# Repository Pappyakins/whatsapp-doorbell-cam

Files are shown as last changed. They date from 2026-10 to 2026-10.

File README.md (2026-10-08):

# WhatsApp Doorbell Cam

A standalone PIR + camera doorbell that snaps a photo of your visitor and delivers it straight to your WhatsApp.

**How it works:** An HC-SR501 PIR watches the doorway on microamps → motion wakes the ESP32-CAM from deep sleep → it snaps a photo → POSTs the JPEG to a small webhook on your home server → the server forwards it to your WhatsApp as a photo message captioned "🔔 Someone's at the door! (Front door, \<time\>)".

No cloud accounts, no subscriptions, no apps phoning home. Your server, your WhatsApp.

> **Status:** build guide complete. Firmware and server photo endpoint are in progress.

## Parts

| Part | Notes |
|---|---|
| AI-Thinker ESP32-CAM module | OV2640 camera, onboard flash LED. ~C$12–18 on AliExpress |
| FTDI USB-to-TTL programmer (3.3V) | **Required** — the ESP32-CAM has no USB port; you cannot flash it without this |
| HC-SR501 PIR motion sensor | The 5-pack variety — you'll have spares |
| 5V USB power adapter | Simplest power option |
| — or — 18650 cell + TP4056 charger (with protection) + 5V boost module | For a truly wireless install |
| 470µF electrolytic capacitor | Across 5V/GND near the board — kills the brownout resets these boards are famous for |
| Jumper wires | |
| 3D-printed enclosure | See Enclosure |

## Power

- Taking a photo + WiFi POST: ~250–300mA for ~10–15 seconds, roughly 1mAh per visitor.
- Deep sleep on a stock board: ~5mA idle (the onboard AMS1117 regulator's quiescent current dominates, not the chip) → about 3–4 weeks on a 3000mAh 18650.
- Same cell with the regulator-bypass mod (feed 3.3V direct, remove the AMS1117): ~0.1mA idle → several months.
- **Recommendation:** USB 5V wall wart if there's an outlet near the door. Zero power anxiety, no charging, no mods. Battery only if the spot truly has no outlet.

## Wiring

- 5V supply → ESP32-CAM `5V` pin, GND → `GND`. 470µF cap across 5V/GND close to the board.
- PIR: `VCC` → 5V, `GND` → GND, `OUT` → **GPIO 13** (RTC-capable, so the ESP32 wakes from deep sleep directly on it — no transistor hack needed).
- Flashing only: FTDI `TX` → `U0R`, `RX` → `U0T`, `GND` → `GND`, `GPIO 0` → `GND` while flashing, then press `RST`. Release GPIO 0 after the flash.

## Server

New endpoint on the home server (same box that runs the text-alert webhook):

- `POST /api/doorbell-photo` — multipart form with the JPEG (`photo`) plus the shared `token`.
- The server saves the photo and sends it to WhatsApp via the Evolution API `sendMedia` call, captioned "🔔 Someone's at the door! (Front door, \<time\>)".
- The same 3-minute cooldown as the text alerts applies, so a lingering visitor doesn't spam you.

## Firmware (in progress)

1. PIR goes high → ESP32 wakes from deep sleep (ext1 wake on GPIO 13).
2. Camera init, snap at SVGA (800x600 — good detail, small enough to POST fast).
3. Optional: flash LED on GPIO 4 fires for night captures.
4. WiFi connect (10s timeout) → POST photo → wait for PIR line to drop → back to deep sleep.

## Enclosure

- 3D-printable case with a window for the PIR Fresnel dome (**must stay exposed**), a window for the camera lens, and an optional flash-LED window if you use it as a night illuminator.
- Mount ~1.5m beside the door, aimed down the walkway, away from direct sun and HVAC vents.
- Keep the ESP antenna area clear of metal.

## 3D-printed case (`case/`)

Ready-to-print STLs, generated by `case/generate_case.py` (true CSG solids
built with manifold3d via the project venv at `../.venv` — edit the
dimensions there if your boards differ). Both STLs are single watertight
solids that open directly in Bambu Studio; assembly dimensions, exploded
view, parts list and wiring are in `case/doorbell-cam-assembly-drawing.pdf`
(generated by `case/make_drawing.py`):

- `doorbell-cam-body.stl` — 96 × 70 × 34.5 mm pebble body with a smooth
  rounded-rectangle silhouette (12 mm corner radius), 2.5 mm walls. The
  front face has two flush circular bezels: a **26 mm bore** for the
  HC-SR501 Fresnel dome and a **20 mm bore** covering the ESP32-CAM lens
  + flash LED. 18650 battery bay (saddle cradle, end stops, zip-tie
  slots), main + charger USB notches in the bottom wall. Four Ø8 corner
  bosses take M3 brass heat-set inserts.
- `doorbell-cam-lid.stl` — matching rounded back lid, 5 mm, with M3
  clearance holes + Ø5.6 counterbores (socket heads sit flush, recesses
  face outward) and two 5 mm round holes for wall screws.

Print settings: PETG recommended (porch/sun/heat), 0.2 mm layers, 3 walls,
15% infill. **No supports needed** — print the body front-face-down
(windows on the build plate) and the lid flat.

Assembly:
1. Mount the boards inside the body with M2.5 standoffs, VHB tape, or hot
   glue, lining the PIR dome and camera lens up with their windows.
2. Thread the USB cable through the bottom notch.
3. Screw the lid to the wall through the two 5 mm holes (screw heads inside).
4. Close the body onto the lid with four M3 × 10 screws (heads sit
   flush in the lid counterbores).

## Build order

1. Order the ESP32-CAM + FTDI programmer (a few weeks on AliExpress).
2. Firmware + server photo endpoint.
3. Flash and bench-test on the desk.
4. Print the case.
5. Mount by the door.

## Security

Never commit WiFi credentials or the API token to this repo. Keep them in a local secrets file on the device and the server only.

---
Powered by @jakinsCraft

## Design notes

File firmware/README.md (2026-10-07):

# Doorbell Cam firmware

Arduino sketch for the AI-Thinker ESP32-CAM. Deep-sleeps until the PIR
wakes it, snaps an 800x600 JPEG, POSTs it to the home server, blinks the
flash LED, and sleeps again.

## Flashing

1. Install the Arduino IDE + ESP32 board support (esp32 by Espressif).
2. Board: **AI Thinker ESP32-CAM**. Partition scheme: default is fine.
3. Copy `config.h.example` to `config.h` and fill in your Wi-Fi details,
   the server URL, and the device token (Muse gives you the token —
   it must match `doorbell_token.txt` on the server).
4. Connect the FTDI programmer: 3.3V -> 3V3, GND -> GND, TX -> U0R,
   RX -> U0T. Hold **GPIO0 to GND** while pressing RST to enter
   download mode, then upload.
5. **Never commit `config.h`.** It is gitignored.

## Wiring

| ESP32-CAM | Other |
|---|---|
| 5V | Boost +5V out  |
| GND | GND (common) |
| GPIO13 | HC-SR501 OUT |
| GPIO4 | (on-board flash LED) |

- HC-SR501 VCC -> 5V (it wants 4.5–12V), GND -> GND.
- HC-SR501 output is 3.3V logic — safe straight into GPIO13.
- Set the PIR sensitivity/time pots mid-range; the jumper on **H**
  (retrigger) is recommended.
- 18650 (+) -> TP4056 B+/B-, TP4056 OUT -> 5V boost in,
  boost out -> ESP32-CAM 5V. Common ground everywhere.

## Power

Deep sleep draws microamps; the board is awake only ~10–20 seconds per
visitor. A 3000mAh 18650 lasts roughly 1–3 months depending on foot
traffic. The printed case (v3+) has the battery bay, charger USB notch,
and zip-tie retainer groove.

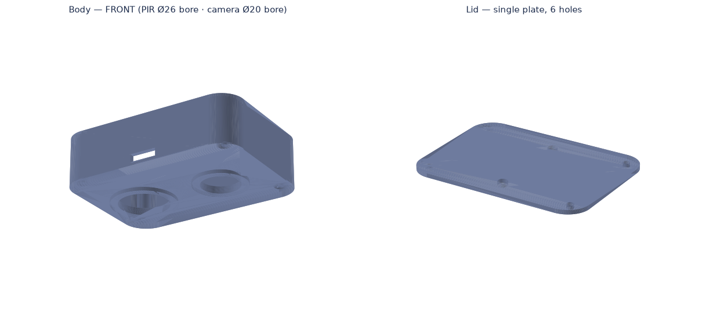
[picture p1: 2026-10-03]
case/preview.png

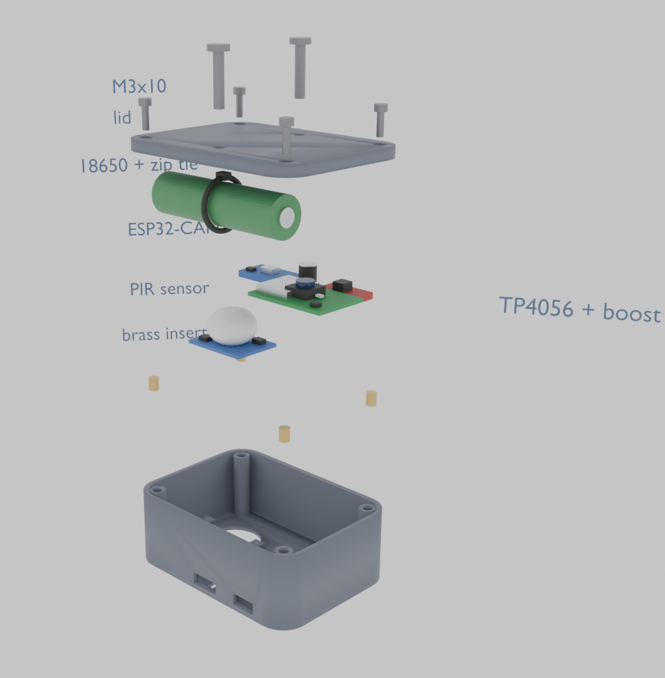
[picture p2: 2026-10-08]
case/render-exploded.png

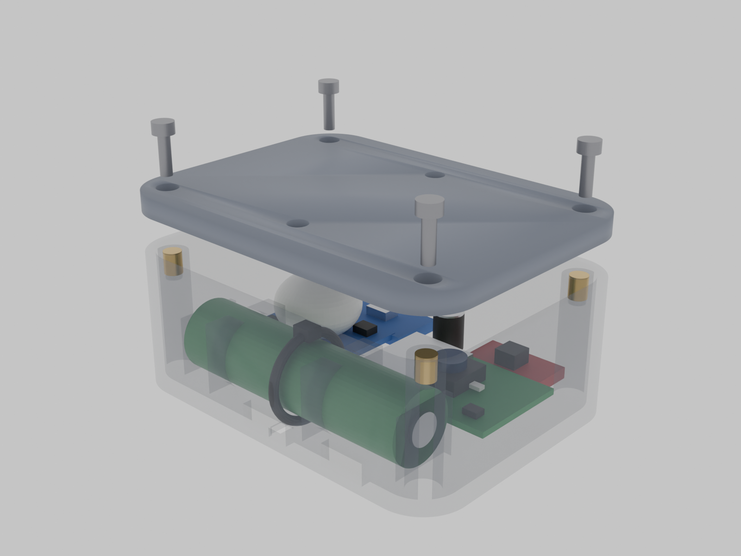
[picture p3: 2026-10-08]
case/render-fitted.png

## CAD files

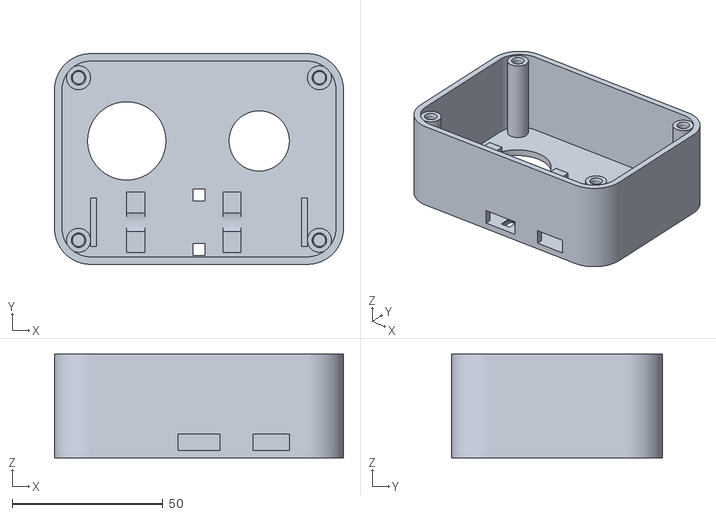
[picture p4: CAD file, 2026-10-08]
case/doorbell-cam-body.stl
96.0 x 70.0 x 34.5

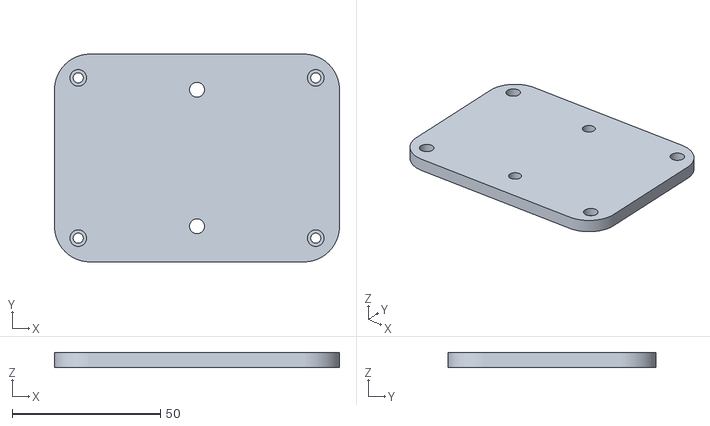
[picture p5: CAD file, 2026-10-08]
case/doorbell-cam-lid.stl
96.0 x 70.0 x 5.00

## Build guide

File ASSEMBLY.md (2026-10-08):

# Doorbell Cam — Assembly Instructions

## Parts checklist

| Qty | Part |
|---|---|
| 1 | Printed body (`doorbell-cam-body.stl`) |
| 1 | Printed lid (`doorbell-cam-lid.stl`) |
| 1 | ESP32-CAM (AI-Thinker, OV2640) |
| 1 | HC-SR501 PIR sensor |
| 1 | 18650 cell, flat-top, 65–68 mm (e.g. Samsung 30Q) |
| 1 | TP4056 charger board **with protection**, micro-USB port |
| 1 | 5V boost converter module |
| 1 | 470µF electrolytic capacitor |
| 4 | M3 brass heat-set inserts (≈4.6 mm OD × 5.7 mm long) |
| 4 | M3×10 socket-head screws (lid → body) |
| 2 | Wall screws + anchors (for the 5 mm lid holes — sized to your wall) |
| 1 | Small zip tie (≈2.5 mm wide) |
| — | Jumper wire, solder |
| — | VHB tape or hot glue (board mounting) |

Tools: 3D printer, soldering iron (also used for the inserts), FTDI USB-to-TTL
programmer (3.3V) for flashing, small Phillips screwdriver, flush cutters.

## 1. Print the case

- PETG recommended (porch, sun, heat). 0.2 mm layers, 3 walls, 15% infill.
- **Body: print front-face-down** (the flat face with the two round bores goes
  on the build plate). **Lid: print flat** (5 mm; the counterbore recesses
  are on the top face). No supports needed for either.

## 2. Install the brass inserts

- Heat your soldering iron to ~200°C (a dedicated insert tip helps, plain tip works).
- Press one M3 insert into each of the 4 corner boss holes, straight down
  until the top sits **flush** with the boss face. Let cool before touching.
- The holes have a small lead-in funnel — the insert should start easily by hand.

## 3. Flash the ESP32-CAM (do this before it goes in the case)

1. Copy `firmware/config.h.example` to `firmware/config.h`; fill in Wi-Fi,
   server URL, and device token.
2. FTDI → ESP32-CAM: 3.3V→3V3, GND→GND, TX→U0R, RX→U0T.
3. Hold **GPIO0 to GND**, press RST, upload the sketch, then release GPIO0.
4. Full flashing details: `firmware/README.md`.

## 4. Wire the power chain (on the bench)

```
18650 (+) → TP4056 B+      18650 (−) → TP4056 B−
TP4056 OUT+ → boost IN+     TP4056 OUT− → boost IN−
boost OUT+ (+5V) → ESP32-CAM 5V pin
boost OUT− (GND) → common ground
470µF capacitor across +5V / GND, as close to the ESP32-CAM as possible
```

- Double-check 18650 polarity before connecting — reverse polarity can kill
  the charger (the protection board is a backstop, not a plan).
- Common ground everywhere: battery −, TP4056, boost, ESP32-CAM, PIR.

## 5. Wire the PIR

| HC-SR501 | Goes to |
|---|---|
| VCC | +5V rail |
| GND | GND |
| OUT | ESP32-CAM **GPIO13** |

- PIR output is 3.3V logic — safe directly into GPIO13.
- Set the sensitivity/time pots to mid-range; put the jumper on **H**
  (retrigger mode).

## 6. Mount the boards in the body

- **ESP32-CAM:** behind the 20 mm bore, lens centred in the hole, **board
  long-side horizontal**. The flash LED sits beside the lens inside the same
  bore. Fix with VHB tape or a dab of hot glue — keep the ESP antenna area
  clear of metal.
- **PIR:** behind the 26 mm bore with the white Fresnel dome poking into it.
  Same fixing method.
- Keep the boards 2–3 mm off the front plate if you can; the bores were
  positioned so nothing fouls the battery bay.

## 7. Fit the battery

1. Lay the 18650 in the saddle cradle (axis along X, between the end stops).
2. Feed the zip tie **up through one floor slot** (from the outside), **over
   the cell**, and **down through the other slot**.
3. Cinch it so the buckle seats in the shallow groove on the outer face.
   Snug, not crushing. Trim the tail.

## 8. Fit the charger and boost boards

- Tape the TP4056 and boost module down **beside** the cradle with VHB tape.
- Line the TP4056's USB port up with the charger notch in the bottom wall —
  that's how you'll plug in to recharge without opening the case.

## 9. Bench-test before closing

1. Power up, wave a hand in front of the PIR.
2. You should get a WhatsApp photo captioned "🔔 Someone's at the door!".
3. If nothing arrives: check the server endpoint is up, the token matches,
   and the PIR OUT line actually goes high (multimeter on GPIO13).

## 10. Mount it

1. Hold the **lid** against the door frame/wall at ~1.5 m height, beside the
   door, aimed down the walkway — away from direct sun and HVAC vents.
2. Fix the lid with 2 screws through the 5 mm holes (**screw heads inside**).
3. Offer the body up and close it with the 4× M3×10 screws into the inserts —
   heads sit flush in the lid counterbores (recesses face outward, away
   from the body). Don't overtighten — snug is enough in PETG.

## Recharging

Plug a USB cable into the TP4056 port through the charger notch. The charger's
onboard LED shows charging/full. A 3000 mAh cell lasts roughly 3–4 weeks on a
stock board (less with heavy foot traffic); the regulator-bypass mod in the
main README stretches that to months.

## Troubleshooting

| Symptom | Likely cause |
|---|---|
| Photo never arrives | Token mismatch, server endpoint down, or no Wi-Fi at the door |
| Board resets when snapping | Missing/weak 5V — check the 470µF cap and boost output under load |
| Constant false triggers | PIR facing sun/vent, sensitivity pot too high |
| Insert spins in boss | Hole printed oversize — a drop of CA glue around the insert saves it |
| Case won't close on lid | Check nothing (boost board, wires) stands taller than the bosses |

---
Powered by @jakinsCraft

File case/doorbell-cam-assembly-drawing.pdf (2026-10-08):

LID (B) — OUTSIDE FACE, 5 THICK

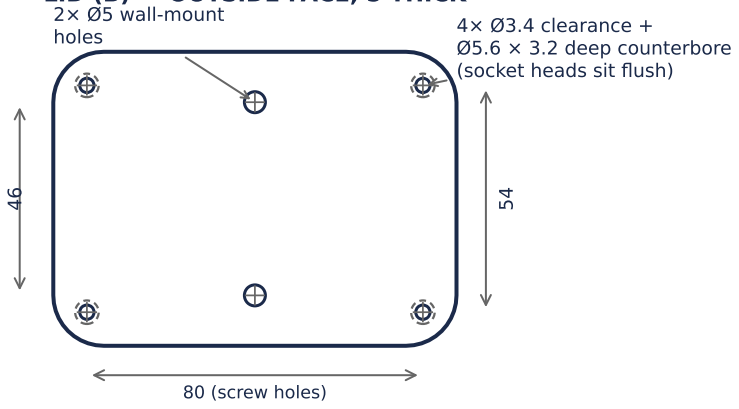
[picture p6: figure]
80 (screw holes); 4× Ø3.4 clearance + Ø5.6 × 3.2 deep counterbore (socket heads sit flush); 2× Ø5 wall-mount holes
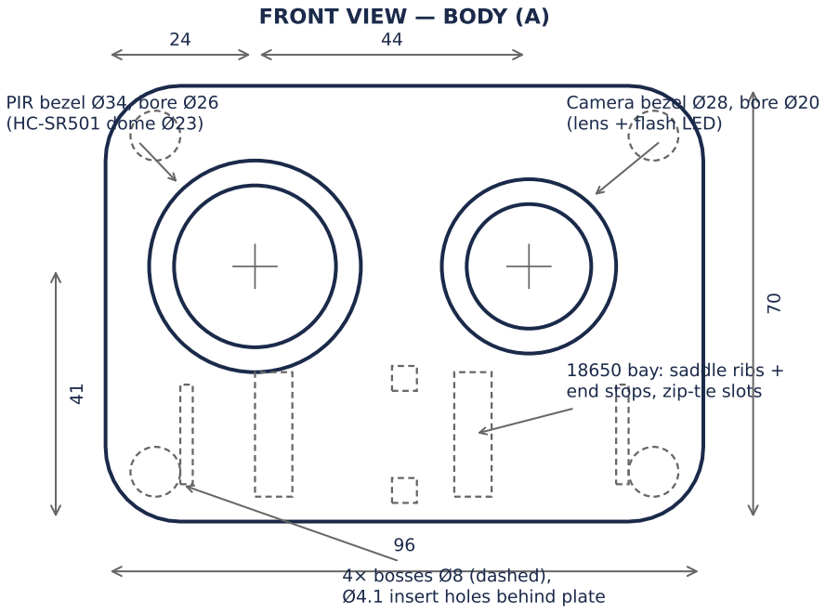
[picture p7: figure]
18650 bay: saddle ribs + end stops, zip-tie slots; FRONT VIEW — BODY (A); PIR bezel Ø34, bore Ø26 (HC-SR501 dome Ø23); Camera bezel Ø28, bore Ø20 (lens + flash LED); 4× bosses Ø8 (dashed), Ø4.1 insert holes behind plate

SIDE VIEW — DEPTHLID (B)

body depth 34.5 lid 5

hollow interior
(2.5 walls all round)

BOTTOM VIEW — USB NOTCH

notches 5.5 tall behind front plate: main USB x 41–55 (14 wide), charger USB x 66–78 (12 wide)

# WhatsApp Doorbell Cam — Pebble Enclosure

Dimensioned views · Body (A) and Lid (B) · STLs in the case folder

Rev 2026-10-08

Units: mm · JakinsCraft

PRINTING
- PETG recommended (porch sun/heat). 0.2 mm layers, 3 walls, 15% infill.
- Body prints FRONT-FACE-DOWN; lid prints flat. No supports needed.
- Both STLs are single watertight solids — they open directly
in Bambu Studio (fixed 2026-10-02; the old files were not).

BEFORE A LONG PRINT
- Test-fit your parts: HC-SR501 dome is Ø23 (bore Ø26); ESP32-CAM boards vary slightly between sellers. Print, check, then commit.
- USB power cable routes out through the bottom notch.
- Press the 4 M3 brass inserts into the bosses (≈200°C iron)
before wiring anything. | Powered by @jakinsCraft

EXPLODED VIEW (schematic, front → back)
lens + flash face the Ø20 bore · PIR dome faces the Ø26 bore

A · BODY

shell with bosses

BOARDS

ESP32-CAM · HC-SR501

B · LID

closes the back

4× M3×10
socket-head
+ brass inserts

charger USB reaches the bottom notch

# | Part | Qty

A | Enclosure body (3D print, PETG) | 1
B | Enclosure lid (3D print, PETG) | 1
1 | ESP32-CAM (AI-Thinker) + OV2640 | 1
2 | HC-SR501 PIR motion sensor | 1
3 | M3 × 10 socket-head screws | 4
4 | M3 brass heat-set inserts | 4
5 | 18650 cell + TP4056 + 5V boost + zip tie | 1 ea.
6 | 470 µF capacitor (across 5V/GND) | 1
7 | FTDI USB-to-TTL programmer * | 1

PARTS LIST (* FTDI is for flashing only)

From | To | Note
18650 +/− | TP4056 B+/B− | check polarity first
TP4056 OUT | boost IN | —
boost +5V | ESP32-CAM 5V | 470 µF across 5V/GND
GND | common everywhere | battery −, PIR, ESP
PIR VCC | 5V rail | —
PIR OUT | ESP32-CAM GPIO 13 | wake-up trigger

WIRING

# Assembly — WhatsApp Doorbell Cam

Exploded stack, parts list, wiring and build order

ASSEMBLY ORDER
1. Print A (face-down) and B (flat). No supports.
2. Press 4 brass inserts into the body bosses, flush.
3. Flash the ESP32-CAM with the FTDI before it goes in.
4. Wire the power chain + PIR per the table below; 470 µF across 5V/GND, close to the ESP32-CAM.
5. Seat the PIR dome in the Ø26 bore, ESP32-CAM lens in the Ø20 bore (board long-side horizontal).
VHB tape or hot glue.
6. Lay the 18650 in the cradle; zip tie up through one floor slot, over the cell, down the other slot.
7. Tape the TP4056 + boost beside the cradle; line the charger USB up with its bottom notch.
8. Bench-test: wave at the PIR → WhatsApp photo.
9. Fix the lid (B) to the wall through the Ø5 holes — counterbore recesses face OUT.
10. Close the body onto the lid with 4× M3×10; heads sit flush in the counterbores.
Fit check: AI-Thinker ESP32-CAM ≈ 40.5 × 27 mm · HC-SR501 board ≈ 32 × 24 mm (typical — verify yours) | Powered by @jakinsCraft

# Pictorial assembly — WhatsApp Doorbell Cam

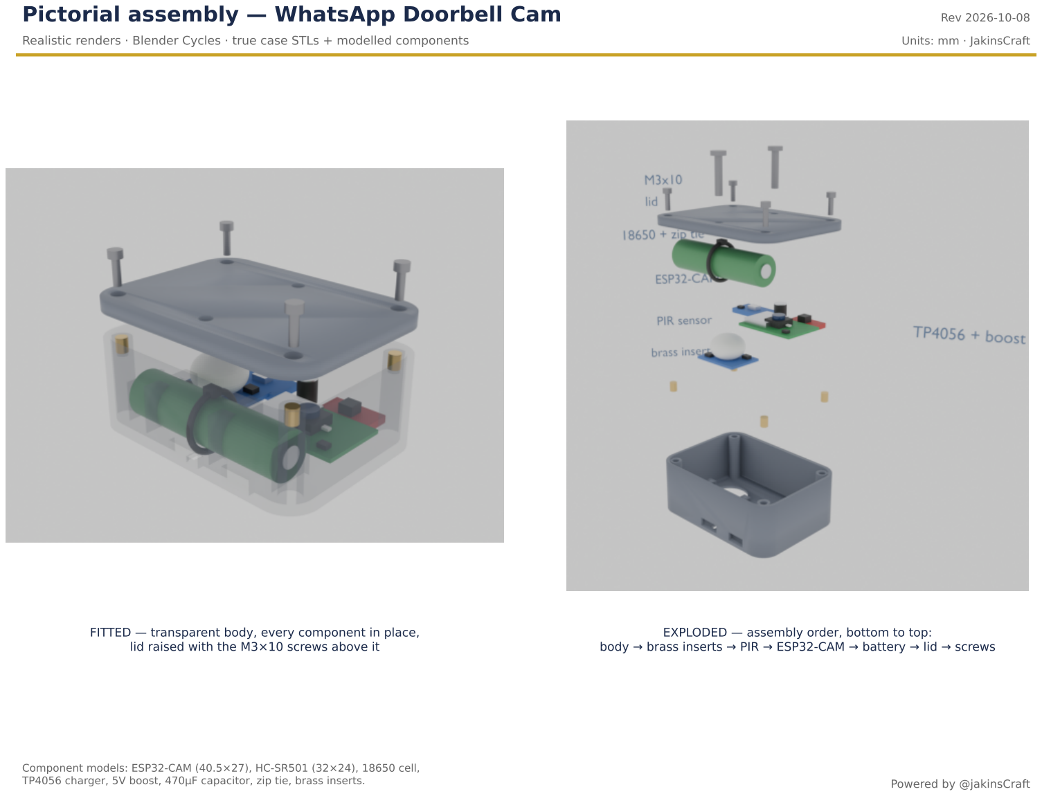
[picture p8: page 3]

Realistic renders · Blender Cycles · true case STLs + modelled components

FITTED — transparent body, every component in place,

lid raised with the M3×10 screws above it

EXPLODED — assembly order, bottom to top: body → brass inserts → PIR → ESP32-CAM → battery → lid → screws

Component models: ESP32-CAM (40.5×27), HC-SR501 (32×24), 18650 cell,
TP4056 charger, 5V boost, 470µF capacitor, zip tie, brass inserts. | Powered by @jakinsCraft

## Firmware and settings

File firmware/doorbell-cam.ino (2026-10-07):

// WhatsApp Doorbell Cam — ESP32-CAM (AI-Thinker) firmware.
//
// Behaviour:
//   * Deep-sleeps at ~microamps. A PIR on GPIO 13 wakes it (EXT0, HIGH).
//   * On wake: captures a JPEG, POSTs it to the home server, blinks the
//     flash LED once, then goes back to deep sleep.
//   * On power-on: sends one "doorbell online" photo, then sleeps.
//
// Copy config.h.example -> config.h and fill in your values.
// config.h is gitignored — never commit Wi-Fi credentials or the token.

#include "esp_camera.h"
#include <WiFi.h>
#include <HTTPClient.h>
#include "mbedtls/base64.h"
#include "config.h"

// ---- AI-Thinker ESP32-CAM pins ----
#define PWDN_GPIO_NUM     32
#define RESET_GPIO_NUM    -1
#define XCLK_GPIO_NUM      0
#define SIOD_GPIO_NUM     26
#define SIOC_GPIO_NUM     27
#define Y9_GPIO_NUM       35
#define Y8_GPIO_NUM       34
#define Y7_GPIO_NUM       39
#define Y6_GPIO_NUM       36
#define Y5_GPIO_NUM       21
#define Y4_GPIO_NUM       19
#define Y3_GPIO_NUM       18
#define Y2_GPIO_NUM        5
#define VSYNC_GPIO_NUM    25
#define HREF_GPIO_NUM     23
#define PCLK_GPIO_NUM     22

#define PIR_GPIO          13          // HC-SR501 OUT -> GPIO13
#define FLASH_GPIO         4          // on-board flash LED
#define WIFI_TIMEOUT_MS   12000

static void go_to_sleep() {
  Serial.println("sleeping...");
  Serial.flush();
  esp_sleep_enable_ext0_wakeup((gpio_num_t)PIR_GPIO, 1);  // wake on PIR HIGH
  esp_deep_sleep_start();
}

static bool init_camera() {
  camera_config_t cfg;
  cfg.ledc_channel = LEDC_CHANNEL_0;
  cfg.ledc_timer   = LEDC_TIMER_0;
  cfg.pin_d0 = Y2_GPIO_NUM;  cfg.pin_d1 = Y3_GPIO_NUM;
  cfg.pin_d2 = Y4_GPIO_NUM;  cfg.pin_d3 = Y5_GPIO_NUM;
  cfg.pin_d4 = Y6_GPIO_NUM;  cfg.pin_d5 = Y7_GPIO_NUM;
  cfg.pin_d6 = Y8_GPIO_NUM;  cfg.pin_d7 = Y9_GPIO_NUM;
  cfg.pin_xclk = XCLK_GPIO_NUM; cfg.pin_pclk = PCLK_GPIO_NUM;
  cfg.pin_vsync = VSYNC_GPIO_NUM; cfg.pin_href = HREF_GPIO_NUM;
  cfg.pin_sscb_sda = SIOD_GPIO_NUM; cfg.pin_sscb_scl = SIOC_GPIO_NUM;
  cfg.pin_pwdn = PWDN_GPIO_NUM; cfg.pin_reset = RESET_GPIO_NUM;
  cfg.xclk_freq_hz = 20000000;
  cfg.pixel_format = PIXFORMAT_JPEG;
  cfg.frame_size = FRAMESIZE_SVGA;       // 800x600 — good detail, small file
  cfg.jpeg_quality = 10;                 // 0(best)..63(worst)
  cfg.fb_count = 1;
  cfg.fb_location = CAMERA_FB_IN_PSRAM;
  cfg.grab_mode = CAMERA_GRAB_LATEST;
  return esp_camera_init(&cfg) == ESP_OK;
}

// base64-encode raw bytes into an Arduino String
static bool b64encode(const uint8_t *in, size_t in_len, String &out) {
  size_t out_len = 0;
  if (mbedtls_base64_encode(NULL, 0, &out_len, in, in_len) != MBEDTLS_ERR_BASE64_BUFFER_TOO_SMALL)
    return false;
  out.reserve(out_len + 32);
  // build in chunks to avoid one giant temporary buffer
  const size_t CHUNK = 3 * 1024;
  uint8_t *tmp = (uint8_t *)malloc(out_len + 1);
  if (!tmp) return false;
  size_t olen = 0;
  bool ok = mbedtls_base64_encode(tmp, out_len + 1, &olen, in, in_len) == 0;
  if (ok) { tmp[olen] = 0; out = "data:image/jpeg;base64," + String((char *)tmp); }
  free(tmp);
  return ok;
}

static bool send_photo(const String &b64photo) {
  WiFi.mode(WIFI_STA);
  WiFi.begin(WIFI_SSID, WIFI_PASS);
  unsigned long t0 = millis();
  while (WiFi.status() != WL_CONNECTED && millis() - t0 < WIFI_TIMEOUT_MS)
    delay(250);
  if (WiFi.status() != WL_CONNECTED) {
    Serial.println("wifi failed");
    return false;
  }
  Serial.print("wifi ok, rssi ");
  Serial.println(WiFi.RSSI());

  HTTPClient http;
  http.begin(SERVER_URL);                      // e.g. http://192.168.2.139:8099/api/doorbell-photo
  http.addHeader("Content-Type", "application/json");
  http.setTimeout(15000);
  String body = "{\"token\":\"" + String(DEVICE_TOKEN) + "\",\"photo\":\"" + b64photo + "\"}";
  int code = http.POST(body);
  Serial.print("POST -> ");
  Serial.println(code);
  String resp = http.getString();
  Serial.println(resp);
  http.end();
  WiFi.disconnect(true);
  WiFi.mode(WIFI_OFF);
  return code == 200;
}

void setup() {
  Serial.begin(115200);
  delay(100);
  pinMode(FLASH_GPIO, OUTPUT);
  digitalWrite(FLASH_GPIO, LOW);
  pinMode(PIR_GPIO, INPUT);

  esp_sleep_wakeup_cause_t cause = esp_sleep_get_wakeup_cause();
  if (cause != ESP_SLEEP_WAKEUP_EXT0 && cause != ESP_SLEEP_WAKEUP_UNDEFINED) {
    go_to_sleep();  // woke for another reason — back to sleep
  }

  if (!init_camera()) {
    Serial.println("camera init failed");
    go_to_sleep();
  }

  // let auto-exposure settle, then grab
  delay(400);
  camera_fb_t *fb = esp_camera_fb_get();
  if (!fb) {
    Serial.println("capture failed");
    go_to_sleep();
  }
  Serial.print("captured ");
  Serial.print(fb->len);
  Serial.println(" bytes");

  String b64;
  bool ok = b64encode(fb->buf, fb->len, b64);
  esp_camera_fb_return(fb);
  if (ok) ok = send_photo(b64);

  if (ok) {  // blink flash to acknowledge
    digitalWrite(FLASH_GPIO, HIGH);
    delay(250);
    digitalWrite(FLASH_GPIO, LOW);
  }
  go_to_sleep();
}

void loop() { /* never reached */ }

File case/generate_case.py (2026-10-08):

#!/usr/bin/env python3
"""Generate STL files for the WhatsApp Doorbell Cam enclosure — pebble style.

v2 (2026-10-02): rebuilt with manifold3d CSG booleans. The v1 script glued
overlapping triangle soup together, which produced non-manifold meshes that
Bambu Studio refused to open. These outputs are true watertight solids.

Design (all mm):
  - Rounded-rectangle "pebble" body, 96 x 70 x 34.5, 2.5 wall, corner r12.
  - Front face with two raised circular bezels (2.5 proud):
      * PIR bezel: outer r17, 26 mm bore for the HC-SR501 Fresnel dome (23 mm)
      * Camera bezel: outer r14, 20 mm bore covering lens + flash LED
  - USB cable notch in the bottom wall (x 41..55, 5.5 tall, behind front plate).
  - 4x corner bosses (8 mm) take M3 brass heat-set inserts
    (4.1 mm blind hole, 7 mm deep, lead-in chamfer); use M3x8 screws.
  - Lid: matching rounded back plate, 5 mm, M3 clearance holes with
    socket-head counterbores on the outer face + 2x 5 mm mount holes.

Coordinates: x 0..96 (width), y 0..70 (height), z 0 at the body's front
outer surface, increasing toward the back opening (z=34.5). The lid STL is
exported in its own frame (z 0..3) so it drops flat onto the build plate.

Print: body FRONT-FACE-DOWN, lid flat. No supports. PETG recommended.
(The front face is fully flat — bezel rings are flush, so the first layer
sits completely on the build plate with no bridging.)

v3 (2026-10-06): battery edition. Adds an 18650 bay in the bottom of the
interior: two saddle ribs cradle the cell (axis along X, centred y=14),
end stops fit 65-68 mm cells (bare or protected flat-top). A zip tie locks
the cell in: it threads up through one floor slot, over the cell, down
through the other slot, and the buckle cinches into a shallow groove on
the outer face. Small boards (TP4056, boost) tape down beside the
cradle — standard DIY practice.

v3.1 (2026-10-08): bezel rings sunk flush with the front face so the body
prints front-face-down with the first layer fully on the build plate —
no bridging, no supports. Added the two zip-tie slots (the v3 groove had
no way to thread the tie through).

v3.3 (2026-10-08): PIR/camera bores raised 3 mm for ESP32-CAM clearance;
screw bosses converted to M3 brass heat-set inserts (8 mm boss, 4.1 mm
blind hole with lead-in chamfer).
v3.4 (2026-10-08): lid thickened to 5 mm with 5.6 mm dia socket-head
counterbores (3.2 deep) on the outer face — M3 socket-head screws sit
flush so the lid mounts flat to the wall.

Run with the project venv:
  ../.venv/bin/python generate_case.py
Outputs: doorbell-cam-body.stl, doorbell-cam-lid.stl (binary STL, mm).
"""
import os
import struct

import numpy as np
from manifold3d import CrossSection, Manifold, set_circular_segments

BASE = os.path.dirname(os.path.abspath(__file__))
set_circular_segments(96)

# ---------------------------------------------------------------- dims ---
CX, CY = 48.0, 35.0                    # case centre
W, H, R = 96.0, 70.0, 12.0             # outer silhouette
WI, HI, RI = 91.0, 65.0, 9.5           # inner cavity (2.5 wall)
T, D = 2.5, 34.5                       # front plate thickness, body depth
PIR = (24.0, 41.0)                     # PIR bezel centre (raised 3 mm for cam clearance)
CAM = (68.0, 41.0)                     # camera bezel centre (raised 3 mm for cam clearance)
BOSS = [(8, 8), (88, 8), (8, 62), (88, 62)]
MOUNT = [(48, 12), (48, 58)]           # lid wall-mount holes


def rounded_prism(w, h, r, z0, depth):
    """Rounded-rectangle prism centred on (CX, CY), from z0 up depth."""
    cs = CrossSection.square([w - 2 * r, h - 2 * r], center=True).offset(r)
    return cs.extrude(depth).translate([CX, CY, z0])


def cyl(r, x, y, z0, depth):
    return Manifold.cylinder(depth, r, circular_segments=96).translate([x, y, z0])


def cyl_x(r, x0, y, z, length):
    """Cylinder with axis along X, spanning x0..x0+length, centred at (y, z)."""
    return (Manifold.cylinder(length, r, circular_segments=96)
            .rotate([0, 90, 0]).translate([x0, y, z]))


def box(x, y, z, sx, sy, sz):
    return Manifold.cube([sx, sy, sz]).translate([x, y, z])


def write_stl(solid, path):
    mesh = solid.to_mesh()
    verts = np.asarray(mesh.vert_properties, dtype=np.float64)[:, :3]
    tris = np.asarray(mesh.tri_verts, dtype=np.int64)
    with open(path, "wb") as f:
        f.write(b"\x00" * 80)
        f.write(struct.pack("<I", len(tris)))
        for a, b, c in tris:
            p, q, s = verts[a], verts[b], verts[c]
            n = np.cross(q - p, s - p)
            ln = np.linalg.norm(n)
            n = n / ln if ln > 0 else n
            f.write(struct.pack(
                "<12f", n[0], n[1], n[2],
                p[0], p[1], p[2], q[0], q[1], q[2], s[0], s[1], s[2]))
            f.write(struct.pack("<H", 0))
    print("wrote", path, len(tris), "triangles,",
          "volume %.0f mm^3" % solid.volume())


# ================================================================= body ==
def build_body():
    body = rounded_prism(W, H, R, 0.0, D)                    # outer shell
    body -= rounded_prism(WI, HI, RI, T, D)                  # hollow interior
    body += cyl(17.0, *PIR, 0.0, T)                           # PIR bezel ring (flush)
    body += cyl(14.0, *CAM, 0.0, T)                           # camera bezel ring (flush)
    for bx, by in BOSS:                                      # screw bosses (8 mm, insert-ready)
        body += cyl(4.0, bx, by, T, 31.5)
    body -= cyl(13.0, *PIR, -T - 1, 10.0)                    # PIR bore (26 mm)
    body -= cyl(10.0, *CAM, -T - 1, 10.0)                    # camera bore (20 mm)
    for bx, by in BOSS:                                      # M3 insert holes (4.1, blind)
        body -= cyl(2.05, bx, by, 27.0, 8.0)
        body -= Manifold.cylinder(1.5, 2.05, 2.6, circular_segments=96).translate([bx, by, 33.0])  # lead-in funnel
    body -= box(41.0, -1.0, T, 14.0, T + 1.5, 5.5)           # USB notch, bottom wall
    body -= box(66.0, -1.0, T, 12.0, T + 1.5, 5.5)           # charger USB notch
    body -= box(45.5, 4.0, 0.0, 5.0, 20.0, 2.0)              # zip-tie groove, outer face
    body -= box(46.0, 3.0, 0.0, 4.0, 4.0, T)                # zip-tie slot, -Y side
    body -= box(46.0, 21.0, 0.0, 4.0, 4.0, T)               # zip-tie slot, +Y side
    # --- 18650 battery bay (cell axis along X at y=14, z-centre 12, r9) ---
    for sx in (24.0, 56.0):                                 # saddle ribs
        saddle = box(sx, 4.0, T, 6.0, 20.0, 18.5)
        saddle -= cyl_x(9.5, sx - 2.0, 14.0, 12.0, 10.0)     # cradle cutout
        body += saddle
    body += box(12.0, 6.0, T, 2.0, 16.0, 15.5)               # end stop, -X
    body += box(82.0, 6.0, T, 2.0, 16.0, 15.5)               # end stop, +X
    return body


# ================================================================== lid ==
LID_T = 5.0                              # lid thickness (fits M3 socket-head counterbore)
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

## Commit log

2026-10-01 Initial build guide for ESP32-CAM WhatsApp doorbell camera
2026-10-02 Add 3D-printable enclosure: body + lid STLs and generator script
    [doorbell-cam-body.stl, doorbell-cam-lid.stl]
2026-10-02 Pebble-style case: rounded body, circular PIR/camera bezels, single-piece lid
    [doorbell-cam-body.stl, doorbell-cam-lid.stl]
2026-10-03 Rebuild case STLs as watertight CSG solids + assembly drawing PDF
    The v1 generator glued overlapping triangle soup together, producing
    non-manifold meshes that Bambu Studio refused to open. The generator
    now builds both parts with manifold3d booleans: every mesh edge is
    shared by exactly 2 triangles (verified), bores/notch/pilot holes
    probe-tested. Dimensions unchanged from the approved pebble design
    (96x70x34.5, PIR bore 26, camera bore 20, lid 3mm).
    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
    [doorbell-cam-body.stl, doorbell-cam-lid.stl]
2026-10-07 Case v3: 18650 battery bay (saddle cradle, end stops, zip-tie groove, charger USB notch)
    [doorbell-cam-body.stl]
2026-10-07 Firmware: ESP32-CAM deep-sleep PIR doorbell with photo POST + server endpoint docs
2026-10-08 Case v3.1: flush bezel rings for support-free face-down printing
    [doorbell-cam-body.stl]
2026-10-08 Case v3.2: zip-tie slots through the bay floor (groove had no thread path)
    [doorbell-cam-body.stl]
2026-10-08 Add ASSEMBLY.md: full build instructions
2026-10-08 Case v3.4: counterbored lid for socket heads; M3 inserts; bores +3mm; drawing PDF regenerated
    [doorbell-cam-body.stl, doorbell-cam-lid.stl]
2026-10-08 Add realistic pictorial assembly renders (Blender Cycles) as drawing page 3
2026-10-18 Tune OV2640 for indoor light: home white-balance mode, lens correction, night exposure, gentler saturation
2026-10-18 Case v3.5: PIR bore 26 -> 24 mm, snug fit for 23 mm dome
2026-10-18 Case v3.6: camera bore 20->12mm (lens only), bezel r14->r10, new 8mm flash LED bore
2026-10-20 Optional CAMERA_NAME per camera: sent with each photo so WhatsApp says which camera fired
2026-10-20 Optional NOTIFY_TO per camera: server honors it only for allowlisted numbers
2026-10-20 Fix IRAM overflow on core 3.3.12: NimBLE + hand-written HTTPS POST
    - BLE provisioning now uses the NimBLE-Arduino library (h2zero)
    instead of the built-in Bluedroid stack; same GATT UUIDs and
    protocol, so the ESP Cam Setup PWA is unchanged.
    - send_photo() drops HTTPClient and POSTs over WiFiClientSecure /
    WiFiClient directly. HTTPClient pulled libc strptime/mktime/tzset
    into IRAM (~4.4 KB). The BT controller itself is most of the IRAM
    cost and is shared by both BLE stacks, so both changes were
    needed: Bluedroid+HTTPClient overflowed iram0_0_seg by 4024
    bytes, NimBLE alone still overflowed by 3992 bytes.
    - Verified locally with arduino-cli, core 3.3.12, esp32cam,
    PartitionSche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
2026-10-20 Case v3.7: fit audit against standard part dimensions
    - Flash bore moved (81,27) -> (51.8,29.7): measured on Ai-Thinker's
    official front photo + an assembled-board photo, the LED centre is
    11.3 right / 18.2 below the lens in board coords, so with the board
    landscape (antenna end right) it lands down-left of the lens. The old
    spot left the LED behind solid plastic.
    - Camera centre (68,41) -> (70,41) for 3+ mm ESP/PIR PCB clearance;
    camera bore 12 -> 13 mm to clear the 9x9 OV2640 lens base.
    - TP4056 + MT3608 get a defined home standing at the back along the
    bottom wall; charger notch moved deep (z 26..31) to actually reach
    the TP4056 USB port; the front USB notch (blocked by the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
2026-10-21 Case v3.8: Pappy's corrections from his own board
    - Board mounts UPRIGHT (antenna top), not landscape: flash bore
    moves to (81.3, 35.8), right of the lens and below it, per his
    check against his physical board.
    - Camera centre (70, 41) -> (70, 54) so the upright board's bottom
    end clears the battery bay; fit check passes clean.
    - Camera bore 13 -> 8 mm (same as flash; lens base seats on plate).
    - PIR bore 24 -> 23 mm (line-to-line with the dome, his spec).
    - Drawing, ASSEMBLY.md and render positions updated to match.
2026-10-21 Case v3.9: flash is to the LEFT of the lens (Pappy's board in hand)
    His physical board settles it: with the ESP32-CAM upright, antenna
    up, the flash LED sits below-left of the lens, not below-right as
    the stock photos measured. Flash bore (81.3, 35.8) -> (58.7, 35.8).
    Board stays upright, camera stays at (70, 54); fit check passes.
2026-10-21 Firmware: BLE setup mode opens on every power-on boot
    Pappy's direction: entering setup must not depend on the photo send
    failing (and the old 2-attempt cap made a healthy cam almost
    impossible to reconfigure away from home). Now a manual power-on
    opens the 5-minute BLE window first; a save/erase restarts onto the
    new settings, a timeout carries on with the normal boot photo and
    send. PIR wakes never open it. Physical setup button comes later.
    Compile-verified: 1,352,713 bytes (43%), huge_app, core 3.3.12.
2026-10-21 Case v3.10: centre the flash bore on the real LED
    First printed case test-fitted: the flash LED sat off-centre in
    its bore. Measured from Pappy's photo of the print, the LED centre
    is 1.1 mm further left and 0.7 mm lower than the stock-photo
    dimensions. Flash bore (58.7, 35.8) -> (59.8, 35.1); check_fit
    LED box and bore check updated to match. Body STL and assembly
    drawing regenerated; lid unchanged.
2026-10-21 Case v3.11: flash bore 2 mm further down, 1.5 mm toward camera
    Pappy's call from the printed case in hand, applied on top of
    v3.10: flash bore (59.8, 35.1) -> (61.3, 33.1), i.e. 8.7 mm left
    and 20.9 mm below the lens centre. check_fit LED box moved with
    it, all clear. Body STL and assembly drawing regenerated.
2026-10-21 Case v3.12: flash bore 2.5 mm back, away from the camera centre
    v3.11 test fit: the 20.9 mm vertical was perfect, the sideways
    move toward the camera was wrong. Flash bore (61.3, 33.1) ->
    (58.8, 33.1), i.e. 11.2 mm left and 20.9 mm below the lens.
    check_fit LED box moved with it, all clear. Body STL and
    assembly drawing regenerated.
2026-10-21 Case v3.13: flash bore 8 -> 12 mm, moved 2 mm up toward camera to (58.8, 35.1), Pappy's call from the v3.12 print
2026-10-22 Case accessories: flash diffuser cap, zip-tie groove cover, UV front artwork
2026-10-24 Lock slider: LOCK command, locked boot skip, GPIO 14 setup button unlock
2026-10-24 Lock slider v2: lock-state characteristic, UNLOCK without restart, button reopens setup without clearing lock
